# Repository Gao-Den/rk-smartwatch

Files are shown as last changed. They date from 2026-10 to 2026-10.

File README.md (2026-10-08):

<div align="center">

Repo Traffic

</div>

## RK Smartwatch

<div style="text-align: left;">
    <img src="rk-smartwatch-stm32f411/hardware/images/rk-smartwatch-overview.png" width=500"/>
</div>
<br>

RK Smartwatch is a smartwatch project developed with the purpose of being a showcase embedded product for applying the RK real-time operating system (Modern Preemptive RTOS) in embedded software development on microcontrollers

Key features:

- Display time, date, month, and year
- Gaming (with Flappy Bird built in)
- Weather forecast

### 1. Purpose
The product helps learners get hands-on with key concepts in embedded software development:

- Developing asynchronous applications on an Event-Driven architecture
- Building and organizing the user interface (UX/UI) with LVGL
- Firmware OTA: Over-the-air firmware updates for STM32 via nRF24L01
- Organizing data transmission and reception (Link) over physical media (Serial, RF, etc.)

### 2. Hardware
#### Components
<div style="text-align: left;">
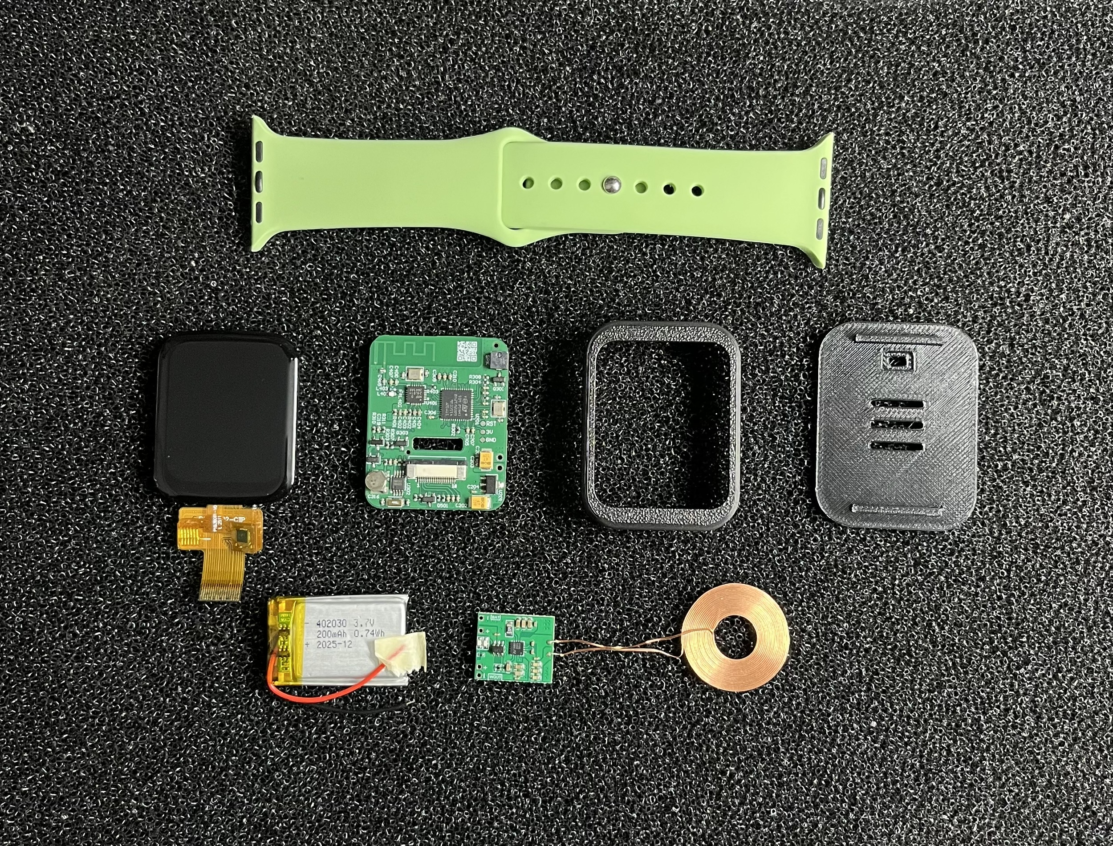
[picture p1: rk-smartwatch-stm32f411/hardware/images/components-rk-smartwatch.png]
    
</div>
<br>

The build consists of:
- Case (3D-printed)
- PCBA board
- Battery & Wireless charging
- Apple Watch strap

#### PCB Assembly
<div style="text-align: left;">
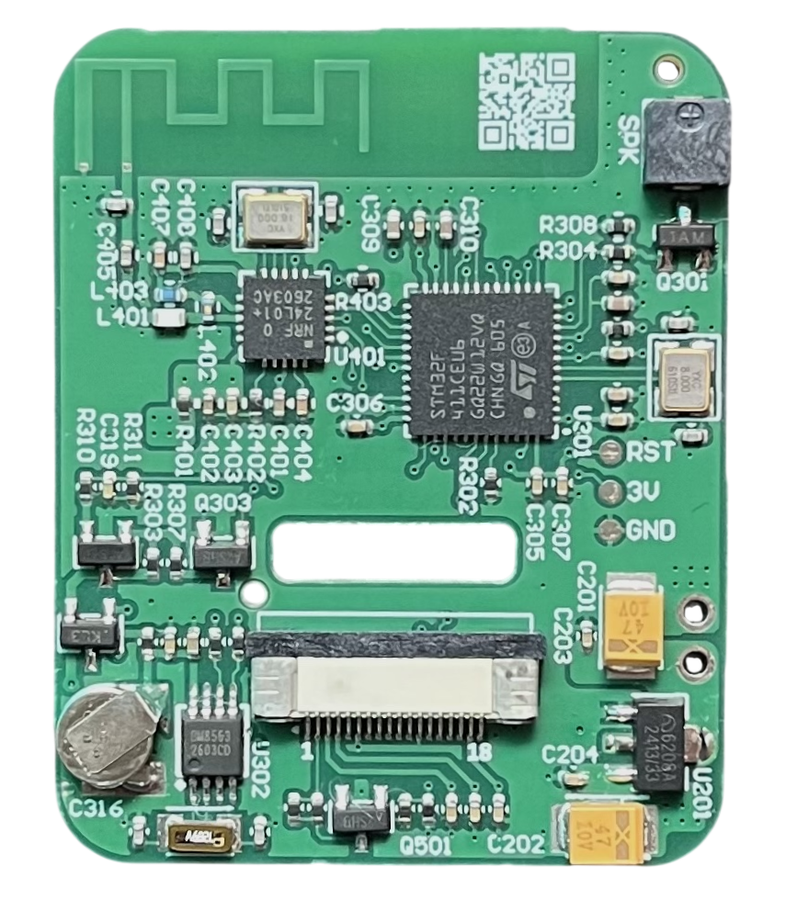
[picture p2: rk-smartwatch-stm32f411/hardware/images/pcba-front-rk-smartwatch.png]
    
</div>
<br>

The board is designed in accordance with DFM (Design for Manufacturing) standards.

Manufacturing resources: [Download](https://github.com/Gao-Den/rk-smartwatch/tree/main/rk-smartwatch-stm32f411/hardware/manufacturing)

#### Mechanical
<div style="text-align: left;">
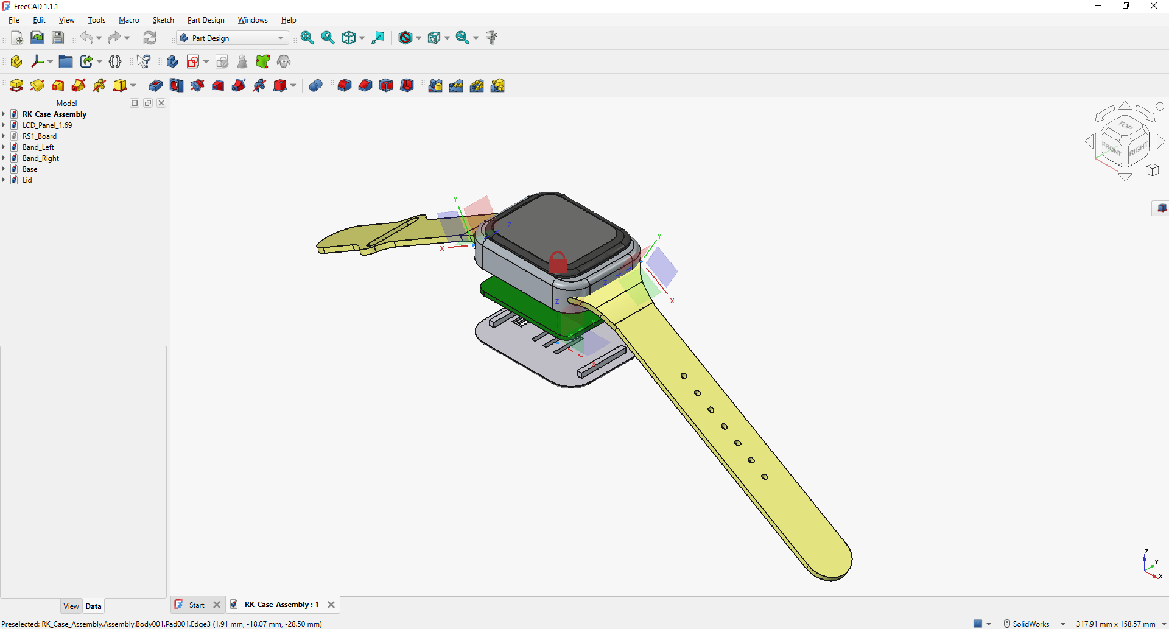
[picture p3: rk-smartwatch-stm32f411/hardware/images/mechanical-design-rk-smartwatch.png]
    
</div>
<br>

The project resources include the attached 3D-printable files.

3D Print: [Download](https://github.com/Gao-Den/rk-smartwatch/tree/main/rk-smartwatch-stm32f411/hardware/mechanical/3d-part)

#### UX/UI Design
<div style="text-align: left;">
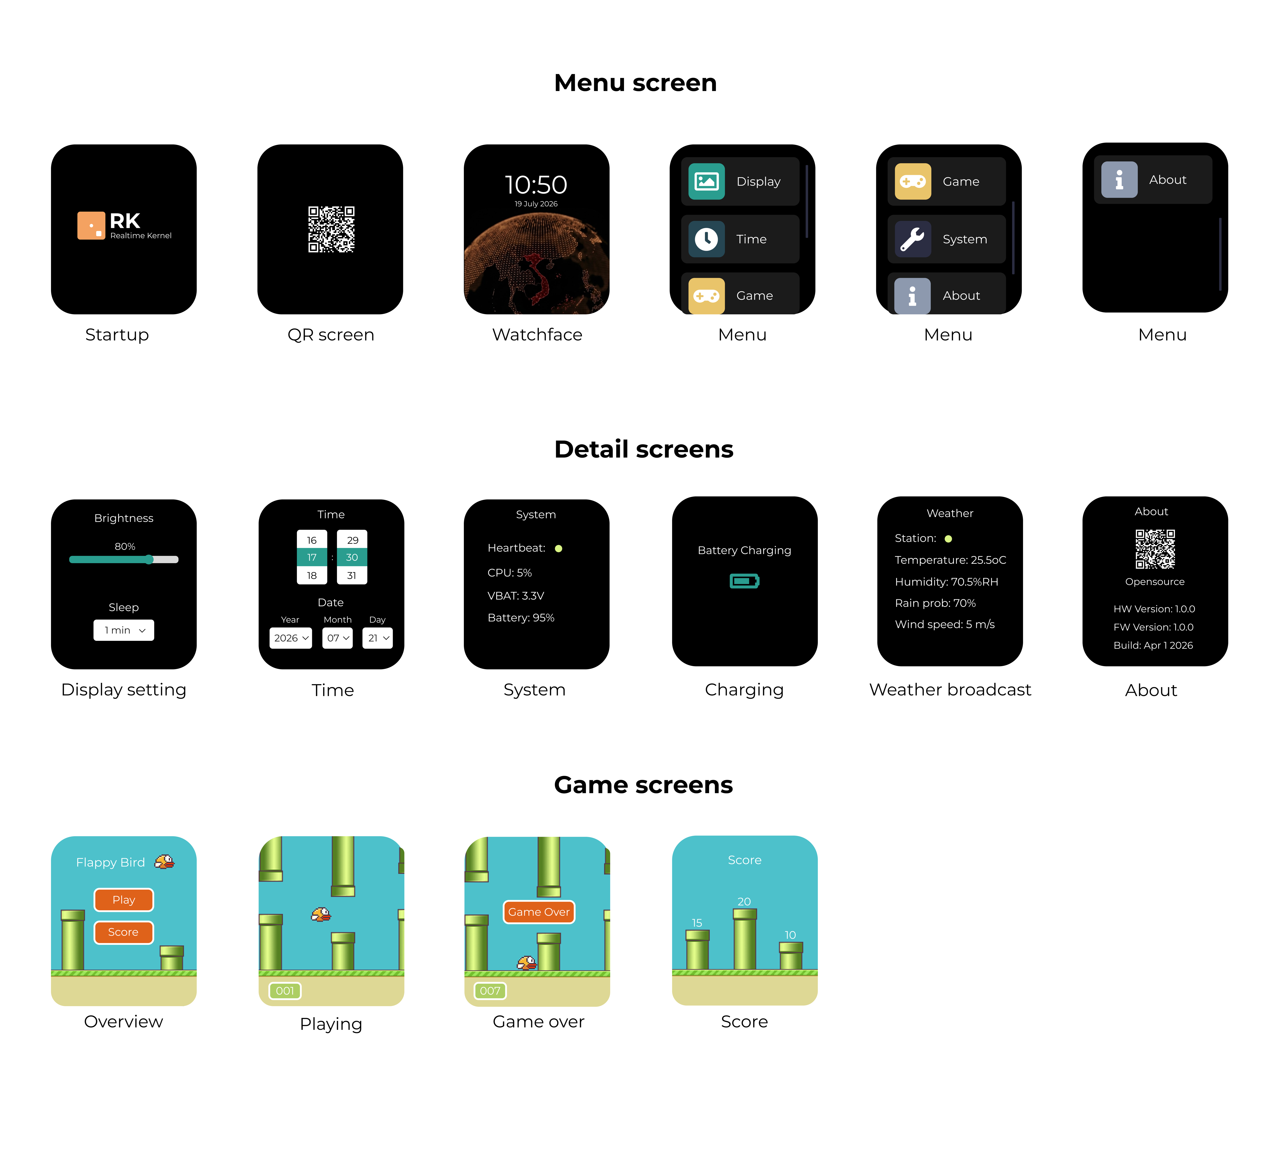
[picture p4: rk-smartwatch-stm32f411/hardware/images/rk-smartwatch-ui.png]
    
</div>
<br>

The interface and screen transitions are designed in Figma. Design reference: [Download](https://github.com/Gao-Den/rk-smartwatch/tree/main/rk-smartwatch-stm32f411/application/sources/app/screen/references)

### 3. Firmware:

| Resource | Description |
| --- | ---
| rk-smartwatch-stm32f411 | The RK Smartwatch |
| rk-flash | The firmware update application for the watch |
| rk-link | The programmer that takes data from the flashing application and packages it into packets for transmission over RF |
| esp32-s3-weather-station | The weather station that broadcasts weather packets to the watch over RF |

### 4. References:

| Topic | Link |
| --- | ---
| RKOS | https://github.com/Gao-Den/rkos |
| AK Embedded Base Kit | https://github.com/ak-embedded-software/ak-base-kit-stm32l151 |
| Active Object Model | https://www.state-machine.com/doc/AN_Active_Objects_for_Embedded.pdf |

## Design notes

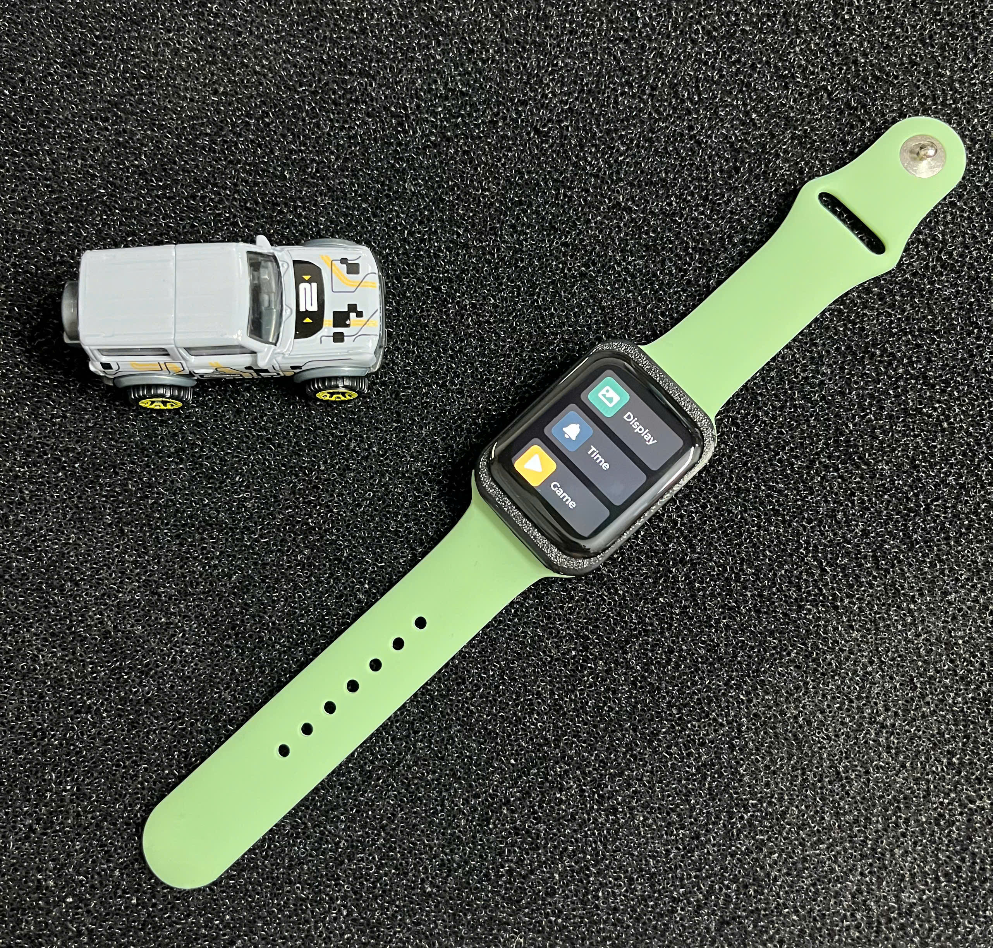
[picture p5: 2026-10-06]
rk-smartwatch-stm32f411/hardware/images/rk-smartwatch-overview.png

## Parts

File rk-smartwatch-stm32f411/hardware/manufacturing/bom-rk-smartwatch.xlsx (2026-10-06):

Smart Watch RS1.PrjPcb
# | Comment | Designator | Footprint | LCSC Part Number | Manufacturer Part Number | Manufacturer | Quantity | Description | Assembly Type | Link
1 | 47uF | C201, C202 | CASE-B_3528 | C136658 | CA45-B-10V-47uF-K | CEC(Shenzhen Zhenhua XinYun Elec) | 2 | 47uF 10V -55℃~+125℃ 2.4Ω@100kHz ±10% CASE-B-3528-19(mm) Tantalum Capacitors ROHS | SMT Assembly
2 | 0.1uF | C203, C204, C303, C304, C305, C306, C307, C308, C312, C313, C318, C501, C502, C503 | C_0402 | C1525 | CL05B104KO5NNNC | Samsung Electro-Mechanics | 14 | 100nF 0402 16V X7R ±10% Multilayer Ceramic Capacitors MLCC - SMD/SMT ROHS | SMT Assembly
3 | 22pF | C301, C302, C409, C410 | C_0402 | C1555 | 0402CG220J500NT | FH (Guangdong Fenghua Advanced Tech) | 4 | 22pF 0402 50V C0G ±5% Multilayer Ceramic Capacitors MLCC - SMD/SMT ROHS | SMT Assembly
4 | 4.7uF | C309, C310, C311 | C_0402 | C23733 | CL05A475MP5NRNC | Samsung Electro-Mechanics | 3 | 4.7uF 0402 10V X5R ±20% Multilayer Ceramic Capacitors MLCC - SMD/SMT ROHS | SMT Assembly
5 | 12pF | C314, C315 | C_0402 | C1547 | 0402CG120J500NT | FH (Guangdong Fenghua Advanced Tech) | 2 | 12pF 0402 50V C0G ±5% Multilayer Ceramic Capacitors MLCC - SMD/SMT ROHS | SMT Assembly
6 | 1uF | C317, C401 | C_0402 | C52923, C157353 | CL05A105KA5NQNC, 0402X105K100NT | Samsung Electro-Mechanics, FH (Guangdong Fenghua Advanced Tech) | 2 | 1uF 0402 16V X7R ±10% Multilayer Ceramic Capacitors MLCC - SMD/SMT ROHS, 1uF 0402 10V X5R ±10% Multilayer Ceramic Capacitors MLCC - SMD/SMT ROHS | SMT Assembly
7 | 10nF | C319, C403 | C_0402 | C15195, C1524 | CL05B103KB5NNNC, 0402B103K500NT | Samsung Electro-Mechanics, FH (Guangdong Fenghua Advanced Tech) | 2 | 10nF 0402 50V X7R ±10% Multilayer Ceramic Capacitors MLCC - SMD/SMT ROHS | SMT Assembly
8 | 1nF | C402 | C_0402 | C1523 | 0402B102K500NT | FH (Guangdong Fenghua Advanced Tech) | 1 | 1nF 0402 50V X7R ±10% Multilayer Ceramic Capacitors MLCC - SMD/SMT ROHS | SMT Assembly
9 | 33nF | C404 | C_0402 | C60425 | 0402B333K160NT | FH (Guangdong Fenghua Advanced Tech) | 1 | 33nF 0402 16V X7R ±10% 0402 Multilayer Ceramic Capacitors MLCC - SMD/SMT ROHS | SMT Assembly
10 | 1.5pF | C405 | C_0402 | C1552 | 0402CG1R5C500NT | FH (Guangdong Fenghua Advanced Tech) | 1 | 1.5pF 0402 50V C0G Multilayer Ceramic Capacitors MLCC - SMD/SMT ROHS | SMT Assembly
11 | 1pF | C406 | C_0402 | C1550 | 0402CG1R0C500NT | FH (Guangdong Fenghua Advanced Tech) | 1 | 1pF 0402 50V C0G Multilayer Ceramic Capacitors MLCC - SMD/SMT ROHS | SMT Assembly
12 | 2.2nF | C407 | C_0402 | C1531 | 0402B222K500NT | FH (Guangdong Fenghua Advanced Tech) | 1 | 2.2nF 0402 50V X7R ±10% Multilayer Ceramic Capacitors MLCC - SMD/SMT ROHS | SMT Assembly
13 | 4.7pF | C408 | C_0402 | C1569 | 0402CG4R7C500NT | FH (Guangdong Fenghua Advanced Tech) | 1 | 4.7pF 0402 50V C0G Multilayer Ceramic Capacitors MLCC - SMD/SMT ROHS | SMT Assembly
14 | BAT54C | D301 | SOT-23-3_L2.9-W1.6-P1.90-LS2.8-BR | C14308 | BAT54CLT1G | ON Semicon | 1 | SCHOTTKY BARRIER DIODES (SBD) SOT-23(SOT-23-3) ROHS | SMT Assembly
15 | FPC-05F-18PH20 | J501 | FPC-SMD_18P-P0.50_FPC-05F-18PH20 | C2856802 | FPC-05F-18PH20 | XUNPU | 1 | -25℃~+85℃ 0.3mm 0.5mm 18P 2mm 500mA 50V Bottom Contact Hinged Lid Phosphor bronze Surface Mount, Right Angle Tin SMD,P=0.5mm,Surface Mount，Right Angle FFC, FPC (Flat Flexible) Connector Assemblies ROHS | SMT Assembly
16 | 3.9nH | L401 | L_0402 | C317939 | FHW0402UC3N9JST | FH (Guangdong Fenghua Advanced Tech) | 1 | 3.9nH 840mA ±5% 66mΩ 0402 Inductors (SMD) ROHS | SMT Assembly
17 | 8.2nH | L402 | L_0402 | C317946 | FHW0402UC8N2JST | FH (Guangdong Fenghua Advanced Tech) | 1 | 8.2nH 680mA ±5% 100mΩ 0402 Inductors (SMD) ROHS | SMT Assembly
18 | 2.7nH | L403 | L_0402 | C317935 | FHW0402UC2N7KST | FH (Guangdong Fenghua Advanced Tech) | 1 | 2.7nH 640mA ±10% 120mΩ 0402 Inductors (SMD) ROHS | SMT Assembly
19 | FUET-4020C | LS301 | Buzzer SMD | C41410568 | FUET-4020C | FUET | 1 | -30℃~+70℃ 100mA 2V~4V 2mm 3V 4kHz 4mm 4mm SMD SMD,4x4mm Buzzers ROHS | SMT Assembly
20 | MMBT3904 | Q301 | SOT-23-3 | C20526 | MMBT3904 | Changjiang Electronics Tech (CJ) | 1 | MMBT3904 TRANSISTORS (NPN/PNP) NPN 200MA 40V SOT-23(SOT-23-3) ROHS | SMT Assembly
21 | SI2301 | Q302 | SOT-23-3_L2.9-W1.3-P1.90-LS2.4-BR | C10487 | SI2301CDS-T1-GE3 | Vishay Intertech | 1 | 1 P-Channel 1.6W -55℃~+150℃ 10nC@4.5V 142mΩ@2.5V 1V 20V 3.1A 405pF 55pF 75pF P-Channel SOT-23 MOSFETs ROHS | SMT Assembly
22 | SI2302CDS | Q303, Q501 | SOT-23-3_L2.9-W1.3-P1.90-LS2.4-BR | C10488 | Si2302CDS-T1-GE3 | Vishay Intertech | 2 | 1 N-channel 2.9A 20V 3.5nC@10V,4.5V 550mW 75mΩ@2.5V 850mV N-Channel SOT-23 MOSFETs ROHS | SMT Assembly
23 | 10k | R301, R302, R308, R311, R504 | R_0402 | C25744 | 0402WGF1002TCE | UNI-ROYAL(Uniroyal Elec) | 5 | 10kΩ 0402 50V 62.5mW Thick Film Resistors ±1% Chip Resistor - Surface Mount ROHS | SMT Assembly
24 | 100k | R303 | R_0402 | C25741 | 0402WGF1003TCE | UNI-ROYAL(Uniroyal Elec) | 1 | 100kΩ 0402 50V -55℃~+155℃ 62.5mW Thick Film Resistor ±1% ±100ppm/℃ Chip Resistor - Surface Mount ROHS | SMT Assembly
25 | 1k | R304, R503 | R_0402 | C11702 | 0402WGF1001TCE | UNI-ROYAL(Uniroyal Elec) | 2 | 1kΩ 0402 50V 62.5mW Thick Film Resistors ±1% Chip Resistor - Surface Mount ROHS | SMT Assembly
26 | 4.7k | R305, R306 | R_0402 | C25900 | 0402WGF4701TCE | UNI-ROYAL(Uniroyal Elec) | 2 | 4.7kΩ 0402 50V -55℃~+155℃ 62.5mW Thick Film Resistor ±1% ±100ppm/℃ Chip Resistor - Surface Mount ROHS | SMT Assembly
27 | 0R | R307, R401 | R_0402 | C17168 | 0402WGF0000TCE | UNI-ROYAL(Uniroyal Elec), Uniroyal Elec | 2 | 0Ω 0402 50V -55℃~+155℃ 62.5mW Thick Film Resistor ±1% ±800ppm/℃ Chip Resistor - Surface Mount ROHS, 0Ω 0402 62.5mW Thick Film Resistors 50V ±800ppm/℃ ±1%Chip Resistor - Surface Mount ROHS | SMT Assembly
28 | 120R | R309 | R_0402 | C25079 | 0402WGF1200TCE | UNI-ROYAL(Uniroyal Elec) | 1 | 120Ω 0402 50V -55℃~+155℃ 62.5mW Thick Film Resistor ±1% ±100ppm/℃ Chip Resistor - Surface Mount ROHS | SMT Assembly
29 | 20k | R310 | R_0402 | C25765 | 0402WGF2002TCE | UNI-ROYAL(Uniroyal Elec) | 1 | 20kΩ 0402 50V 62.5mW Thick Film Resistors ±1% Chip Resistor - Surface Mount ROHS | SMT Assembly
30 | 22k | R402 | R_0402 | C25768 | 0402WGF2202TCE | Uniroyal Elec | 1 | 22kΩ 0402 62.5mW Thick Film Resistors 50V ±100ppm/℃ ±1% Chip Resistor - Surface Mount ROHS | SMT Assembly
31 | 22R | R403 | R_0402 | C25092 | 0402WGF220JTCE | Uniroyal Elec | 1 | 22Ω 0402 62.5mW Thick Film Resistors 50V ±1% ±100ppm/℃ Chip Resistor - Surface Mount ROHS | SMT Assembly
32 | 220R | R501, R502 | R_0402 | C25091 | 0402WGF2200TCE | UNI-ROYAL(Uniroyal Elec) | 2 | 220Ω 0402 50V -55℃~+155℃ 62.5mW Thick Film Resistor ±1% ±100ppm/℃ Chip Resistor - Surface Mount ROHS | SMT Assembly
33 | ME6208A30PG | U201 | SOT_89 | C80196 | ME6208A30PG | MICRONE(Nanjing Micro One Elec) | 1 | -45℃~+150℃ 1 150mA 18V 3V 3uA Fixed Positive SOT-89 Voltage Regulators - Linear, Low Drop Out (LDO) Regulators ROHS | SMT Assembly
34 | STM32F411CEU6 | U301 | UFQFPN-48_L7.0-W7.0-P0.50-BL-EP | C60420 | STM32F411CEU6 | STMicroelectronics | 1 | -40℃~+85℃ 1.7V~3.6V 100MHz 128KB 12bit 32 Bit 36 512KB ARM Cortex-M4 Built-in FLASH UFQFPN-48(7x7) Microcontrollers (MCU/MPU/SOC) ROHS | SMT Assembly
35 | BM8563EMA | U302 | MSOP-8_L3.0-W3.0-P0.65-LS5.0-BL | C269878 | BM8563EMA | GATEMODE(捷茂微) | 1 | MSOP-8 Real-time Clocks (RTC) ROHS | SMT Assembly
36 | NRF24L01P-R | U401 | QFN-20_L4.0-W4.0-P0.50-BL-EP | C8791 | NRF24L01P-R | NORDIC | 1 | NRF24L01P-R SPI QFN-20_4x4x05P RF Transceiver ICs ROHS | SMT Assembly
37 | 8MHz | X301 | CRYSTAL_SMD3225_4P | C2682774 | X32258MSB4SI | YXC Crystal Oscillators | 1 | 8MHz 20pF 120Ω -40℃~+85℃ Crystal Oscillator ±10ppm ±20ppm SMD3225-4P Crystals ROHS | SMT Assembly
38 | 32.768kHz | X302 | CRYSTAL-SMD_L3.2-W1.5 | C841881 | Q13FC13500005 | Seiko Epson | 1 | 32.768kHz 12.5pF ±10ppm SMD3215-2P Crystals ROHS | SMT Assembly
39 | 16Mhz | X401 | SMD-3225_4P | C13738 | X322516MLB4SI | Yangxing Tech | 1 | 16MHz SMD Crystal Resonator 9pF ±10ppm ±30ppm -40℃~+85℃ SMD3225-4P Crystals ROHS | SMT Assembly

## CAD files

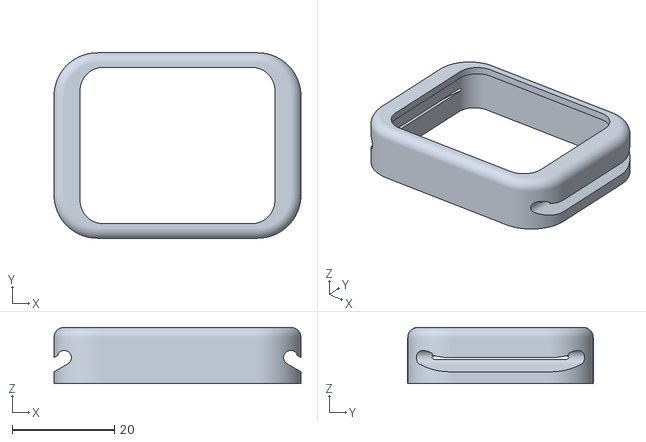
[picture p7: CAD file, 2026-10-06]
rk-smartwatch-stm32f411/hardware/mechanical/3d-part/base-cover-rk-smartwatch.stl
48.2 x 36.2 x 11.0

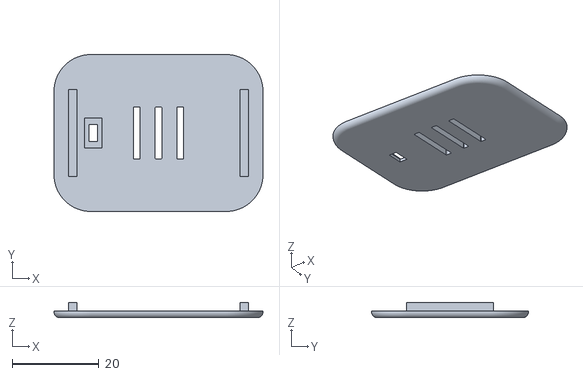
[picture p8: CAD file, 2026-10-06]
rk-smartwatch-stm32f411/hardware/mechanical/3d-part/lid-rk-smartwatch.stl
48.1 x 36.1 x 3.50

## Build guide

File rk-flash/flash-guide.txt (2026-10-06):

.\rk-flash.exe COM20 D:\GaoDen\dev\rk-smartwatch-stm32f411\application\build\rk-smartwatch-stm32f411-v1.0.0.bin 0

.\rk-flash.exe COM20 D:\GaoDen\dev\rk-smartwatch-stm32f411\boot\build\rk-smartwatch-stm32f411-boot-v1.0.0.bin 1

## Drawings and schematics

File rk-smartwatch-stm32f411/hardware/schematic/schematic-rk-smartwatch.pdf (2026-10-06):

# Power.SchD

o

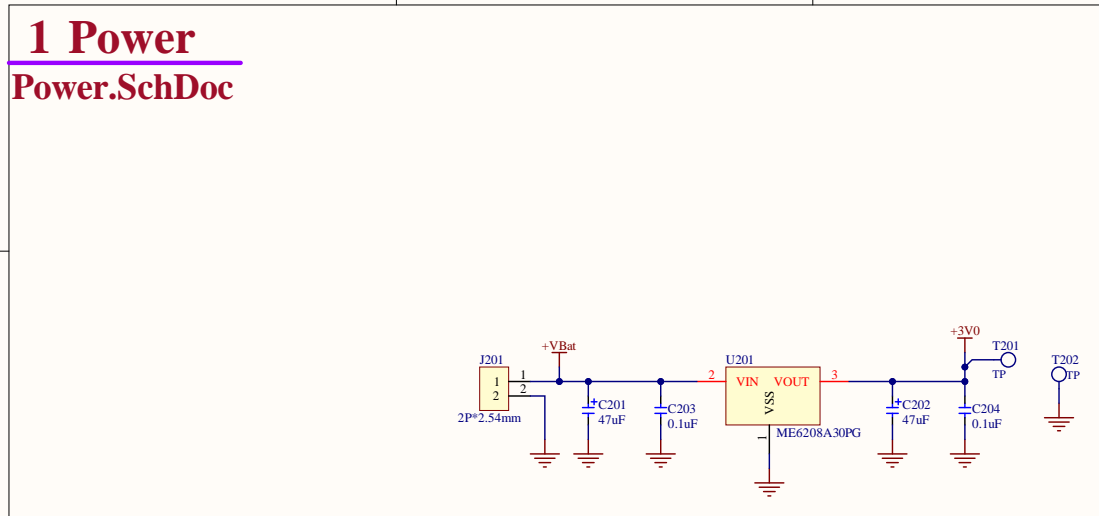
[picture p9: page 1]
DWG; wer.Sch; Smart; Watch RS1.PrjPcb; SmartWatch; 1 Powe r; VSS 1; +VBat

# MCU.SchDoc

# 2 MCU

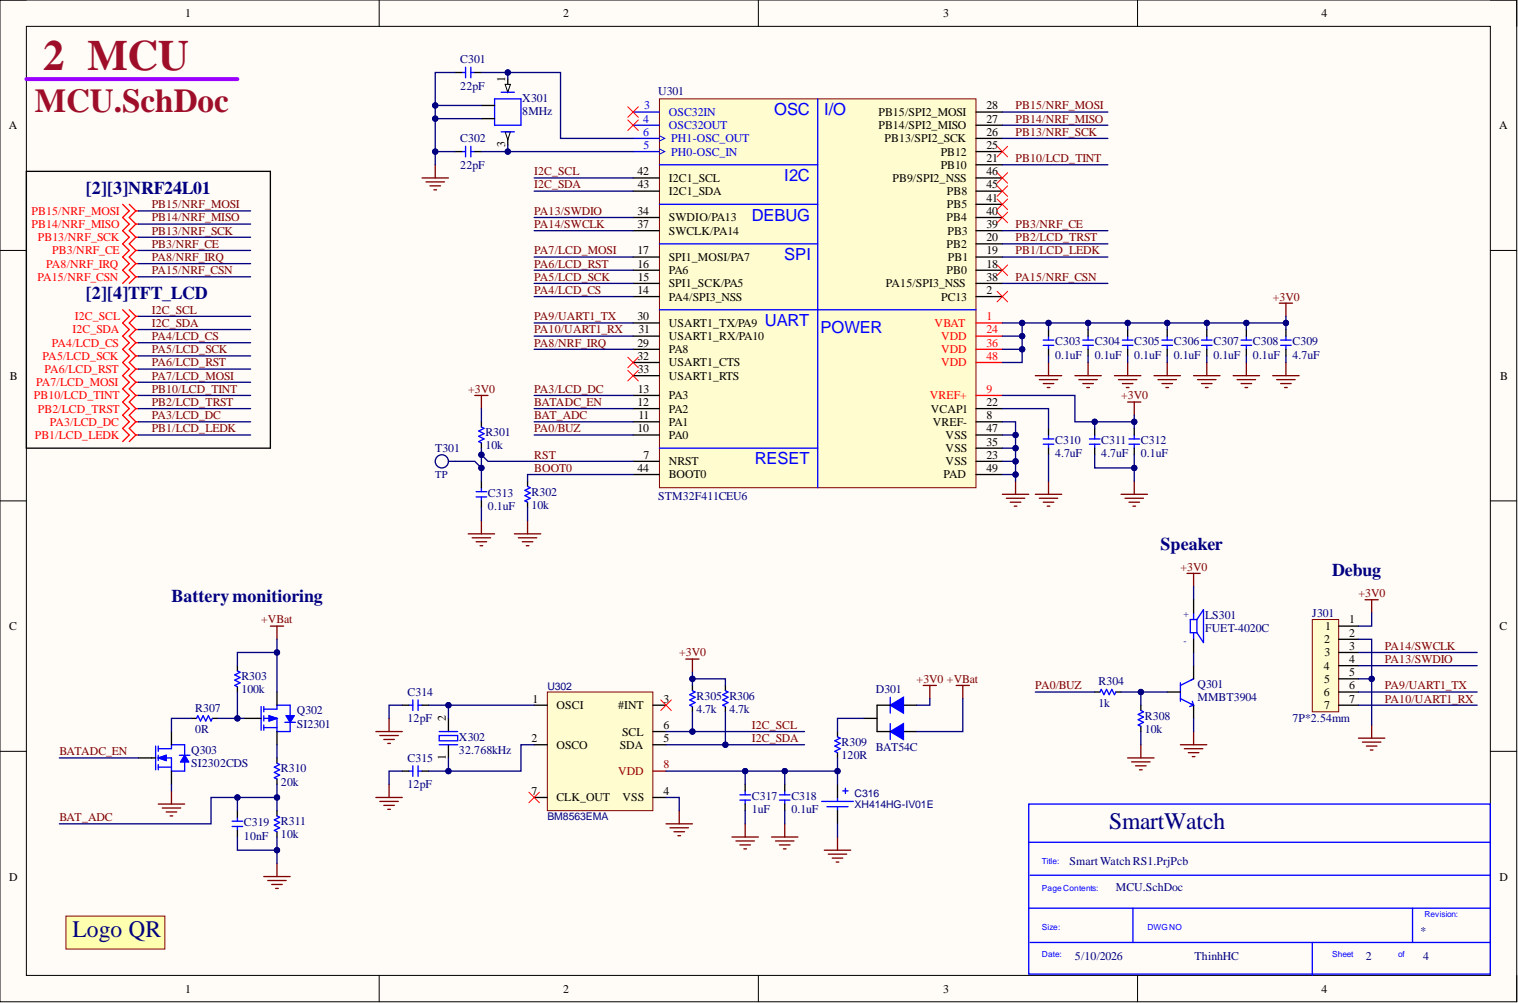
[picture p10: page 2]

# NRF24L01-M.SchDoc

# 3NRF24L01-M

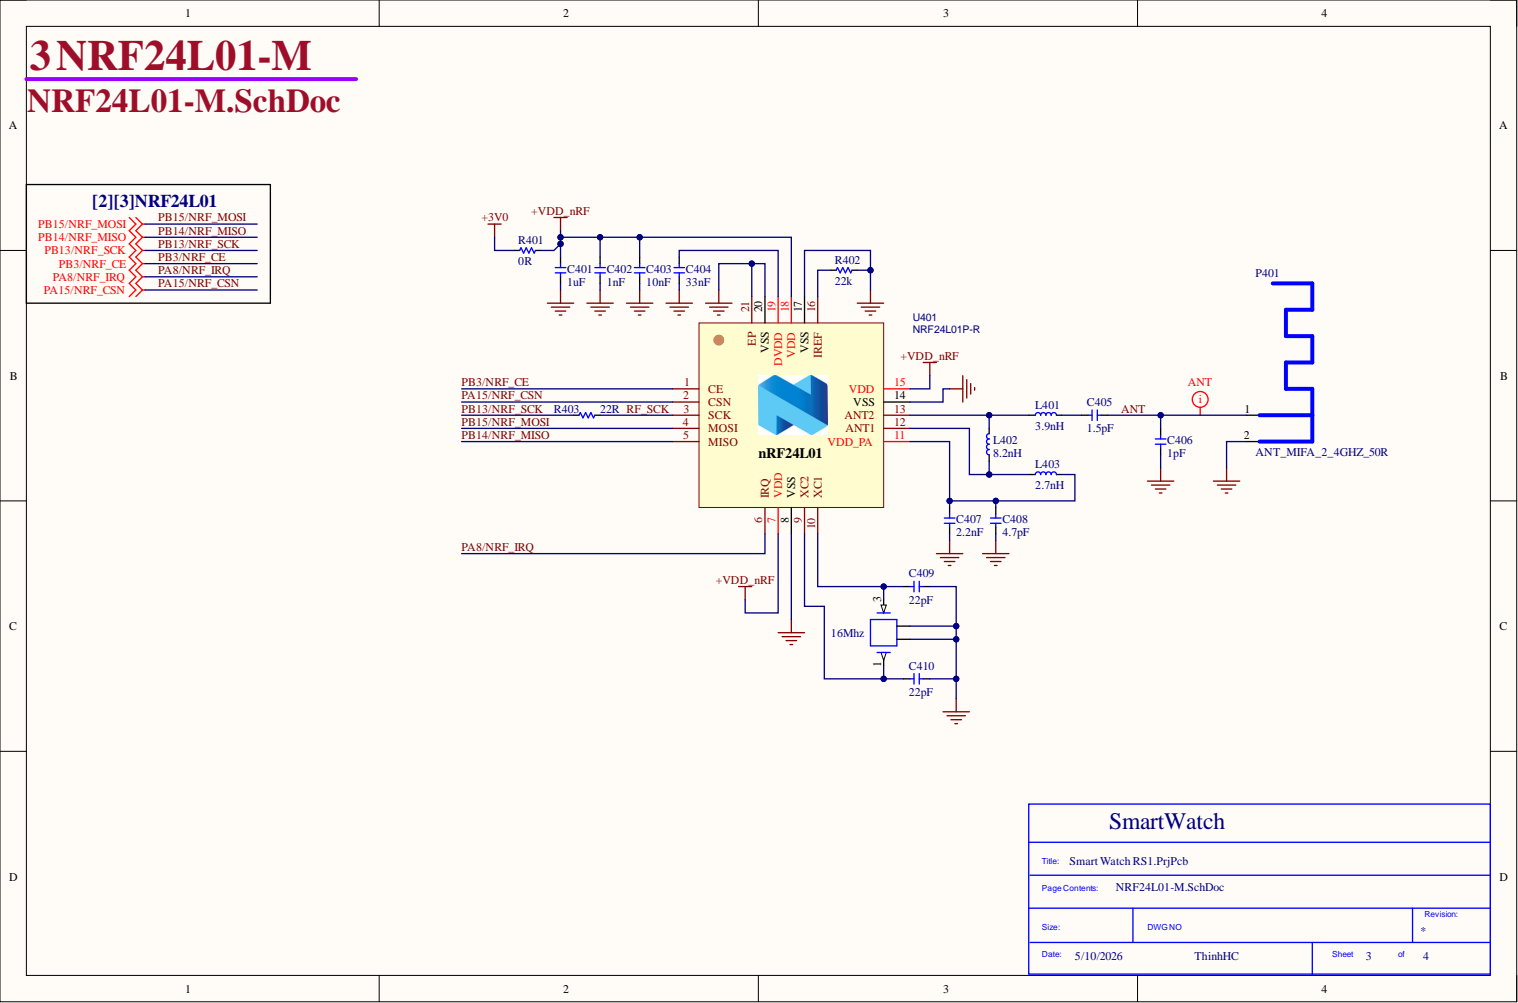
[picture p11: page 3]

IREF 16 VSS 17 VDD 18 DVDD 19 VSS 20 EP 21 nRF24L01

# TFT_LCD.Sch

D

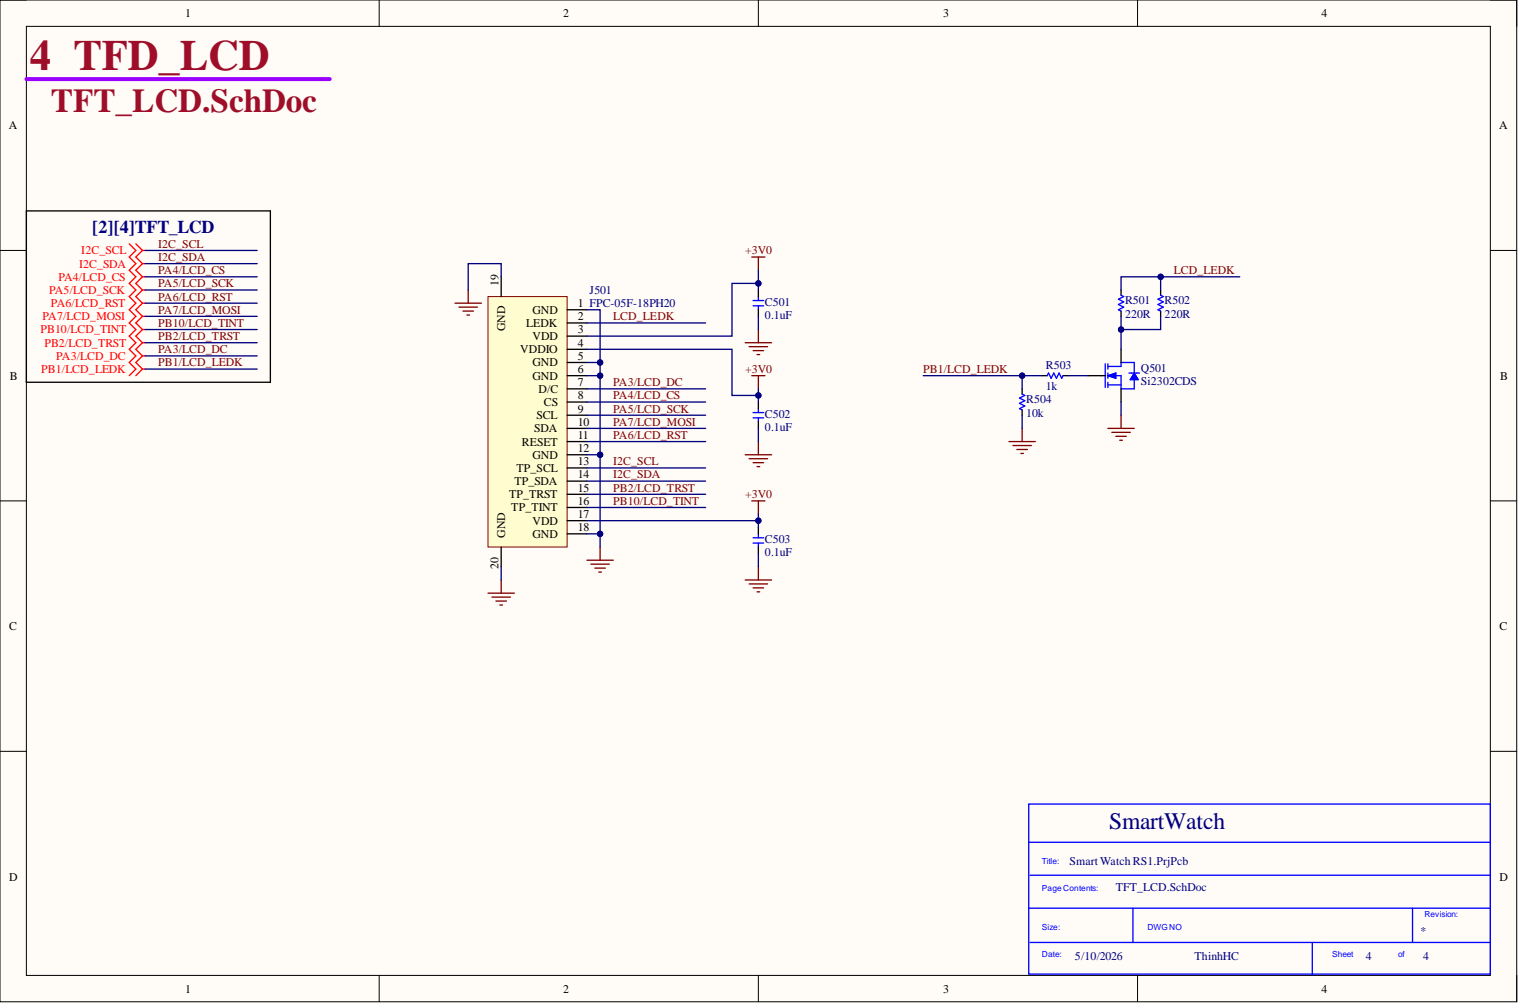
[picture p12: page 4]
I2C_SCL I2C_; A I2C_SCL I2C_; LCD; T PB10/LCD_TINT; DWG; TFT; LCD.Sch; Smart; Watch RS1.PrjPcb; SmartWatch; 4 TFD_LCD; SCL; RESE; TP_SCL; GND 19 GND 20; 1 FPC-0

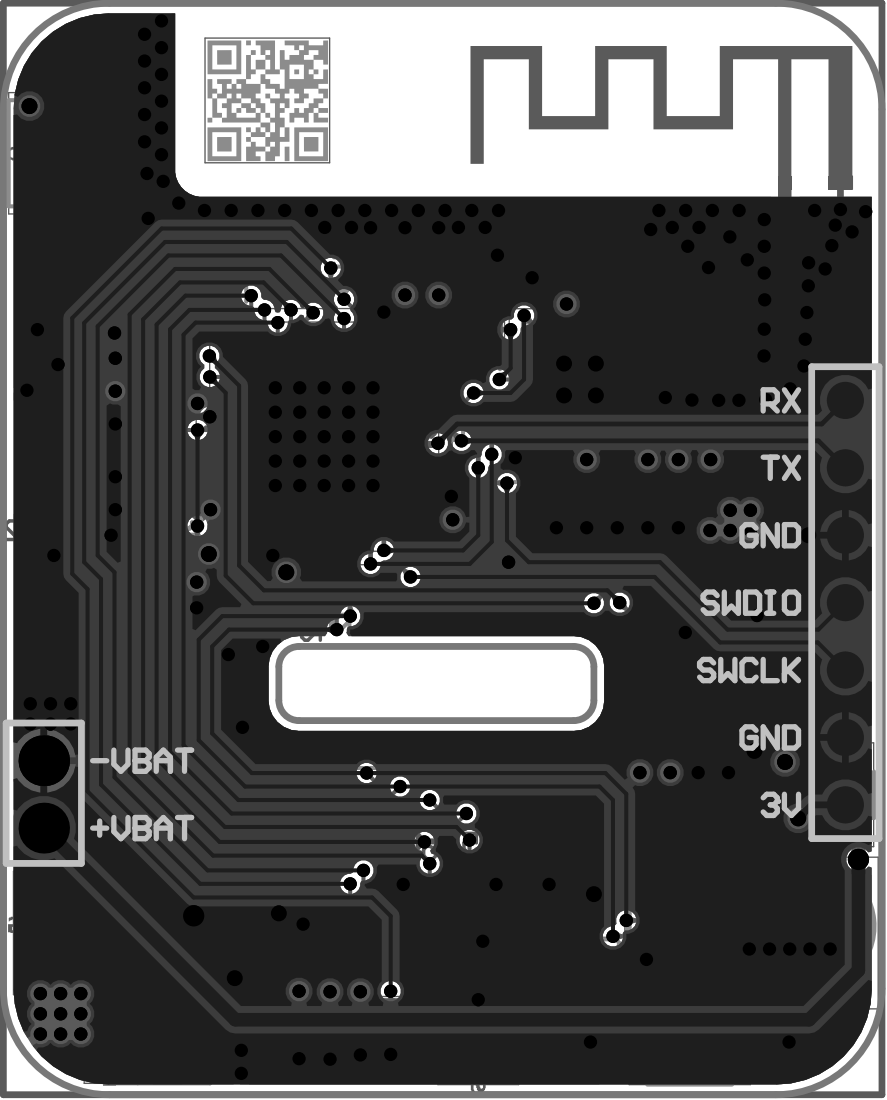
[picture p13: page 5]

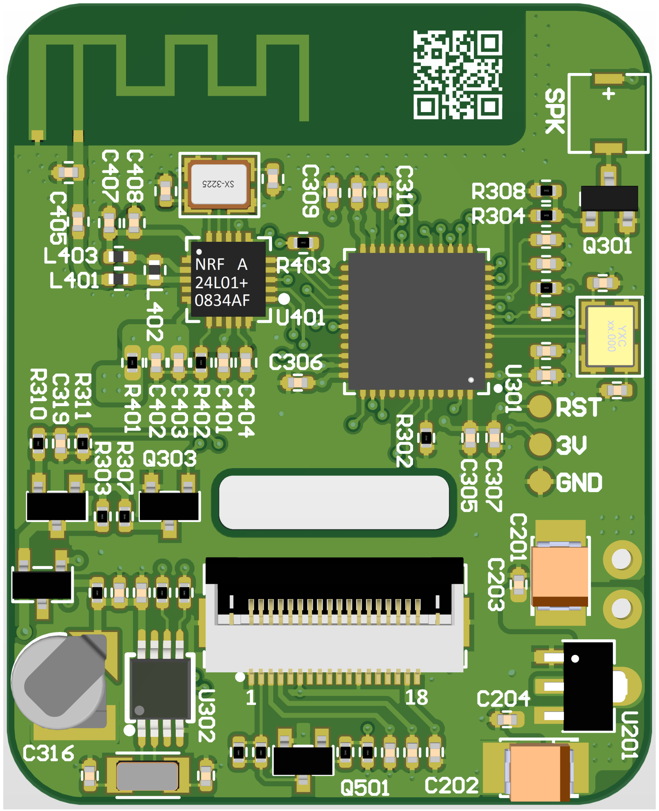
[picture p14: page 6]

# | Comment Designato | | Footprint LCSC Part NumbMeanufacturer Part Number | | | Manufacturer | Quantity | Description | Assembly Type | Link

1 | 47uF | C201, CCASE-B_3528 | | C136658 | CA45-B-10V-47uF-K | CEC(Shenzhen Zhenhua XinYu | 2 | 47uF 10V -55℃~+125℃SMTAssembly
2 | 0.1uF | C203, CC_0402 | | C1 525 | L5B104KO 5NNN | Sam sungEl ectro -Mechanics | 14 | 100nF 0402 16V X7R ±1SMTAssemb ly
3 | 22pF | C301, CC_0402 | | C1555 | 0402CG220J500NT | FH (Guangdong Fenghua Adva | 4 | 22pF 0402 50V C0G ±5%SMTAssem bly
4 | 4.7uF | C309, CC_0402 | | C23733 | CL05A475MP5NRNC | Samsung Electro-Mechanics | 3 | 4.7uF 0402 10V X5R ±2SMTAssem bly
5 | 12pF | C314, CC_0402 | | C1547 | 0402CG120J500NT | FH (Guangdong Fenghua Adva | 2 | 12pF 0402 50V C0G ±5%SMTAssem bly
6 | 1uF | C317, CC_0402 | | C52923, C15735CL05A105KA5NQNC, 0402XSamsungElectro-Mechanics, F | | | 2 | 1uF040216VX7R±10%SM TAsse mbly
7 | 10nF | C319, CC_0402 | | C15195, C1524 | CL05B103KB5NNNC, 0402B1SamsungElectro-Mechanics, F | | 2 | 10nF040250VX7R±10SM TAssem bly
8 | 1nF | C402 | C_0402 | C1523 | 0402B102K500NT | FH (Guangdong Fenghua Adva | 1 | 1nF 0402 50V X7R ±10%SMTAsse mbly
9 | 33nF | C404 | C_0402 | C60425 | 0402B333K160NT | FH (Guangdong Fenghua Adva | 1 | 33nF 0402 16V X7R ±10SM TAssembly
10 | 1.5pF | C405 | C_0402 | C1552 | 0402CG1R5C500NT | FH (Guangdong Fenghua Adva | 1 | 1.5pF 0402 50V C0G MSMTA ssembly
11 | 1pF | C406 | C_0402 | C1550 | 0402CG1R0C500NT | FH (Guangdong Fenghua Adva | 1 | 1pF 0402 50V C0G MultSMT Assembly
12 | 2.2nF | C407 | C_0402 | C1531 | 0402B222K500NT | FH (Guangdong Fenghua Adva | 1 | 2.2nF 0402 50V X7R ±1SMTAssem bly
13 | 4.7pF | C408 | C_0402 | C1569 | 0402CG4R7C500NT | FH (Guangdong Fenghua Adva | 1 | 4.7pF 0402 50V C0G MuSMTA ssmbly
14 | BAT54C | D301 | SOT-23-3_L2.9-W1.6C14308 | | BAT54CLT1G | ON Semicon | 1 | SCHOTTKY BARRIER DSMT Ass embly
15 | FPC-05F-18PH20 | J501 | FPC-SMD_18P-P0.5C2856802 | | FPC -05F-18PH20 | XUNPU | 1 | -25℃~+85℃ 0.3mm 0.5SMTAs sembly
16 | 3.9nH | L401 | L_0402 | C317939 | FHW0402UC3N9JST | FH (Guangdong Fenghua Adva | 1 | 3.9nH 840mA ±5% 66mSMTAssembly
17 | 8.2nH | L402 | L_0402 | C317946 | FHW0402UC8N2JST | FH (Guangdong Fenghua Adva | 1 | 8.2nH 680mA ±5% 100mSM TAssembly
18 | 2.7nH | L403 | L_0402 | C317935 | FHW0402UC2N7KST | FH (Guangdong Fenghua Adva | 1 | 2.7nH 640mA ±10% 120SMTAssembly
19 | FUET-4020C | LS301 | Buzzer SMD | C41410568 | FUET-4020C | FUET | 1 | -30℃~+70℃ 100mA 2VSMTAssembly
20 | MMBT3904 | Q301 | SOT-23-3 | C20526 | MMBT3904 | Changjiang Electronics Tech (C | 1 | MMBT3904 TRANSISTOSM TAssemb ly
21 | SI2301 | Q302 | SOT-23-3_L2.9-W1.3C10487 | | SI2301CDS-T1-GE3 | Vishay Intertech | 1 | 1 P-Channel 1.6W -55℃SMTAssembly
22 | SI2302CDS | Q303, QSOT-23-3_L2.9-W1.3C10488 | | | Si2302CDS-T1-GE3 | Vishay Intertech | 2 | 1 N-channel 2.9A 20V 3.SMTAssembly
23 | 10k | R301, RR_0402 | | C25744 | 0402WGF1002TCE | UNI-ROYAL(Uniroyal Elec) | 5 | 10kΩ 0402 50V 62.5mWSMTAssembly
24 | 100k | R303 | R_0402 | C25741 | 0402WGF1003TCE | UNI-ROYAL(Uniroyal Elec) | 1 | 100kΩ 0402 50V -55℃~SMTAssembly
25 | 1k | R304, RR_0402 | | C11702 | 0402WGF1001TCE | UNI-ROYAL(Uniroyal Elec) | 2 | 1kΩ 0402 50V 62.5mW | SMTAssembly
26 | 4.7k | R305, RR_0402 | | C25900 | 0402WGF4701TCE | UNI-ROYAL(Uniroyal Elec) | 2 | 4.7kΩ 0402 50V -55℃~+SMTAssembly
27 | 0R | R307, RR_0402 | | C17168 | 0402WGF0000TCE | UNI-ROYAL(Uniroyal Elec), Uni | 2 | 0Ω 0402 50V -55℃~+15SMTAssembly
28 | 120R | R309 | R_0402 | C25079 | 0402WGF1200TCE | UNI-ROYAL(Uniroyal Elec) | 1 | 120Ω 0402 50V -55℃~+SMTAssembly
29 | 20k | R310 | R_0402 | C25765 | 0402WGF2002TCE | UNI-ROYAL(Uniroyal Elec) | 1 | 20kΩ 0402 50V 62.5mWSMTAssembly
30 | 22k | R402 | R_0402 | C25768 | 0402WGF2202TCE | Uniroyal Elec | 1 | 22kΩ 0402 62.5mW ThiSM TAssembly
31 | 22R | R403 | R_0402 | C25092 | 0402WGF220JTCE | Uniroyal Elec | 1 | 22Ω 0402 62.5mW ThicSMTAssembly
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

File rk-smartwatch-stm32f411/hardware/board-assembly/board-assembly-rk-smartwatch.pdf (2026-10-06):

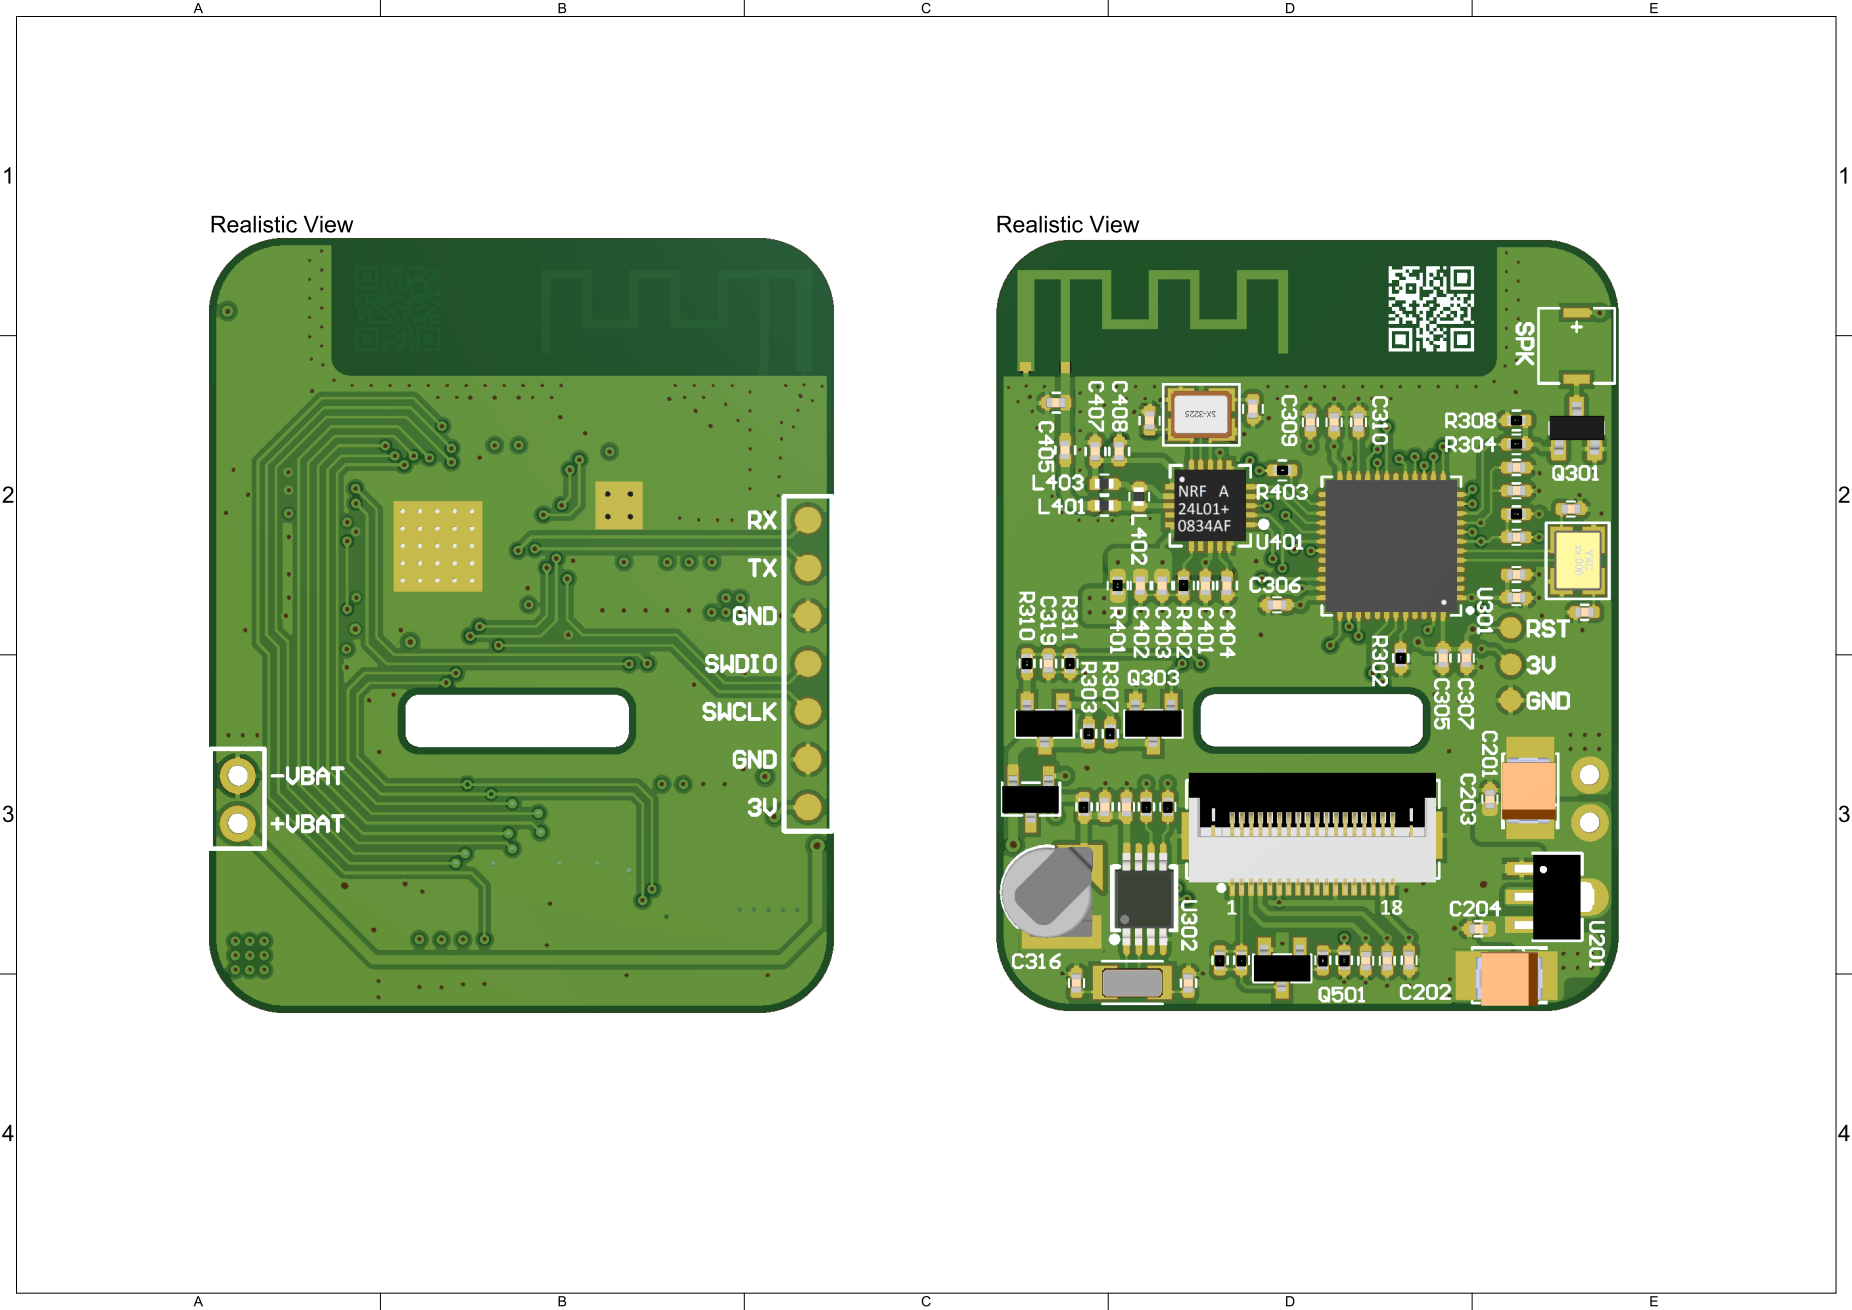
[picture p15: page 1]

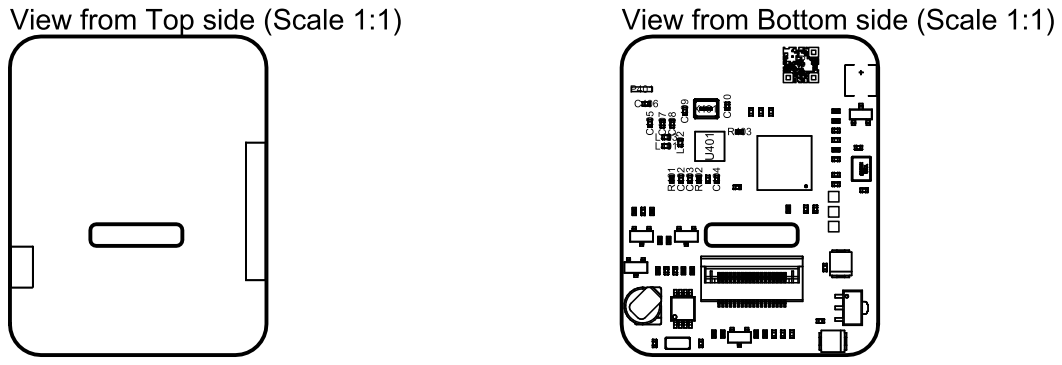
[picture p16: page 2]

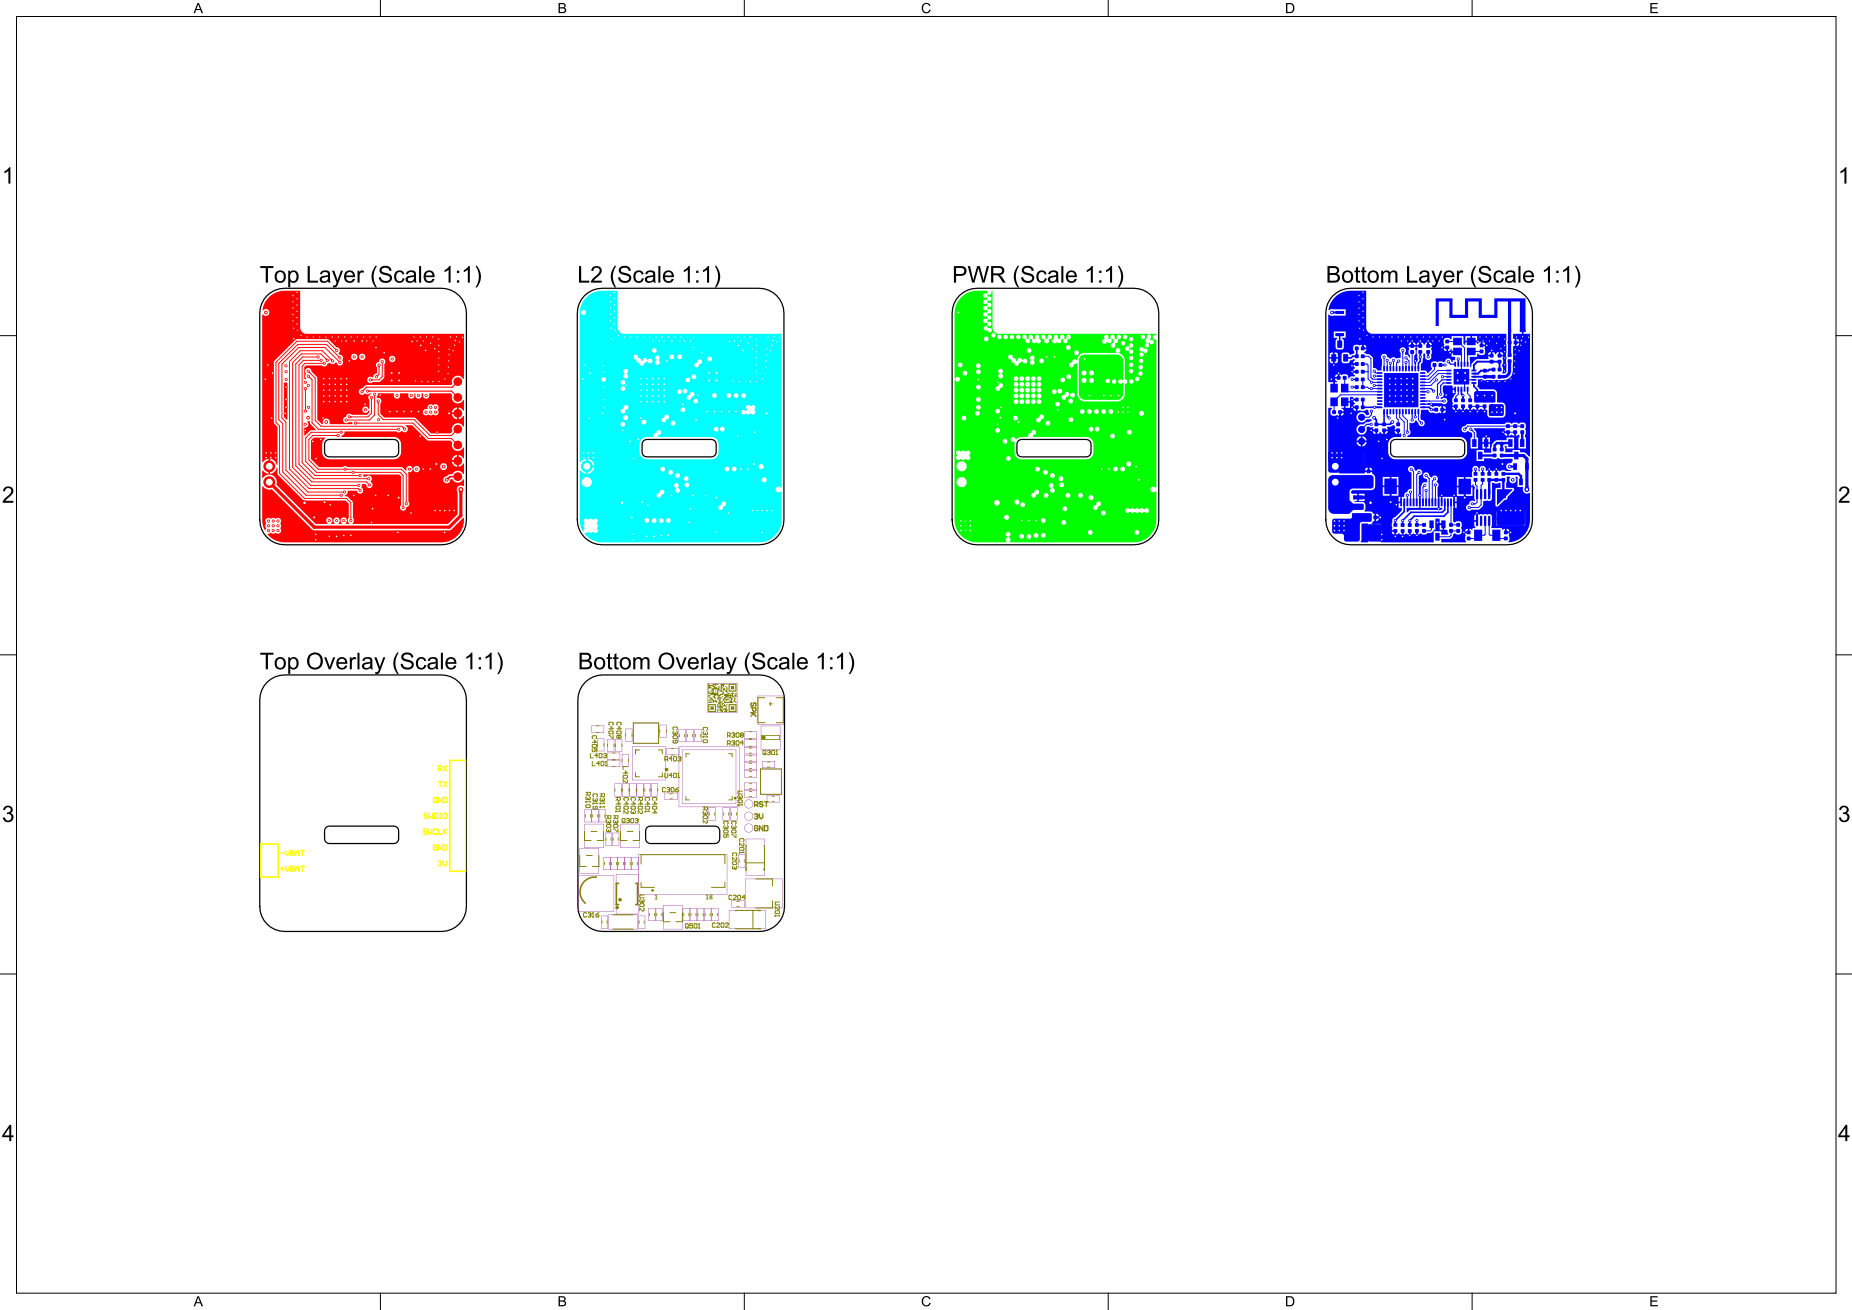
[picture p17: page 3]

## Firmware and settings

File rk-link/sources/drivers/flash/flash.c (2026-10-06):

/**
 ******************************************************************************
 * @file: flash.c
 * @brief: external flash function for W25Q256JVEIQTR NOR Flash
 * @date: 27/08/2024
 * @author: GaoKong
 ******************************************************************************
**/

#include "flash.h"
#include <stdbool.h>

#include "io_cfg.h"
#include "sys_cfg.h"

/* WINBOND commands */
#define WINBOND_W_EN                        0x06    /* write enable */
#define WINBOND_W_DE                        0x04    /* write disable */
#define WINBOND_R_SR1                       0x05    /* read status reg 1 */
#define WINBOND_R_SR2                       0x35    /* read status reg 2 */
#define WINBOND_W_SR                        0x01    /* write status reg */
#define WINBOND_PAGE_PGM                    0x02    /* page program */
#define WINBOND_QPAGE_PGM                   0x32    /* quad input page program */
#define WINBOND_BLK_E_64K                   0xD8    /* block erase 64kb */
#define WINBOND_BLK_E_32K                   0x52    /* block erase 32kb */
#define WINBOND_SECTOR_E                    0x20    /* sector erase 4kb */
#define WINBOND_CHIP_ERASE                  0xC7    /* chip erase */
#define WINBOND_CHIP_ERASE2                 0x60    /* =chip_erase */
#define WINBOND_E_SUSPEND                   0x75    /* erase suspend */
#define WINBOND_E_RESUME                    0x7A    /* erase resume */
#define WINBOND_PDWN                        0xB9    /* power down */
#define WINBOND_HIGH_PERF_M                 0xA3    /* high performance mode */
#define WINBOND_CONT_R_RST                  0xFF    /* continuous read mode reset */
#define WINBOND_RELEASE                     0xAB    /* release power down or hpm/dev id (deprecated) */
#define WINBOND_R_MANUF_ID                  0x90    /* read manufacturer and dev id (deprecated) */
#define WINBOND_R_UNIQUE_ID                 0x4B    /* read unique id (suggested) */
#define WINBOND_R_JEDEC_ID                  0x9F    /* read jedec id = manuf+id (suggested) */
#define WINBOND_READ                        0x03
#define WINBOND_FAST_READ                   0x0B
#define WINBOND_READ_STATUS_REG_1           0x05

#define WINBOND_SR1_BUSY_MASK               0x01    /* status register 1 busy mask */
#define WINBOND_SR1_WEN_MASK                0x02    /* status register 1 write enable mask */

#define WINBOND_WINBOND_MANUF               0xEF    /* winbond manufacturer id */

#define WINBOND_DEFAULT_TIMEOUT             200     /* default timeout */

/* flash enable debug */
#define FLASH_DBG_EN						0

/******************************************************************************
* declare static function
*******************************************************************************/
static void flash_set_write_enable(bool);
static uint8_t flash_wait_to_idle();

/******************************************************************************
* define static function
*******************************************************************************/
void flash_set_write_enable(bool e) {
	flash_cs_low();

	if (e == true) {
		spi1_transfer(WINBOND_W_EN);
	}
	else {
		spi1_transfer(WINBOND_W_DE);
	}

	flash_cs_high();

	sys_ctrl_delay_us(100);
}

uint8_t flash_wait_to_idle() {
	uint8_t reg_1 = 0;
	uint32_t time_out_counter = 10000;	/* 10s */

	flash_cs_low();
	sys_ctrl_delay_us(100);

	spi1_transfer(WINBOND_READ_STATUS_REG_1);

	do {
		reg_1 = spi1_transfer(0x00);
		time_out_counter --;
		sys_ctrl_delay_us(100);
	} while ((reg_1 & 1) && time_out_counter);

	flash_cs_high();

	if (time_out_counter) {
		return FLASH_DRIVER_OK;
	}

	return FLASH_DRIVER_NG;
}

/******************************************************************************
* define public function
*******************************************************************************/
uint8_t flash_read(uint32_t address, uint8_t* pbuf, uint32_t len) {
	uint16_t i;

#if (FLASH_DBG_EN == 1)
	SYS_PRINT("[flash_read] add:0x%x\t%d\n", address, len);
#endif

	flash_wait_to_idle();

	flash_cs_low();

	spi1_transfer(WINBOND_READ);

	spi1_transfer(address >> 16);
	spi1_transfer(address >> 8);
	spi1_transfer(address);

	for(i = 0; i < len; i++) {
		pbuf[i] = spi1_transfer(0x00);
	}

	flash_cs_high();

	return FLASH_DRIVER_OK;
}

uint8_t flash_write(uint32_t address, uint8_t* pbuf, uint32_t len) {
	bool next_page_flag = true;
	uint32_t pbuf_index = 0;

#if (FLASH_DBG_EN == 1)
	SYS_PRINT("[flash_write] add:0x%x\t%d\n", address, len);
#endif

	while (len) {
		if (next_page_flag) {
			next_page_flag = false;

			flash_wait_to_idle();
			flash_set_write_enable(true);

			flash_cs_low();

			spi1_transfer(WINBOND_PAGE_PGM);

			spi1_transfer((address >> 16) & 0xff);
			spi1_transfer((address >> 8)  & 0xff);
			spi1_transfer((address >> 0)  & 0xff);
		}

		spi1_transfer(pbuf[pbuf_index++]);

		address++;
		len--;

		if ((address & 0xff) == 0) {
			next_page_flag = true;
			if (len) {
				flash_cs_high();
			}
		}
	}

	flash_cs_high();

	return flash_wait_to_idle();
}

uint8_t flash_erase_sector(uint32_t address) {

	if (address % 0x1000) {
		return FLASH_DRIVER_NG;
	}

#if (FLASH_DBG_EN == 1)
	SYS_PRINT("[flash_erase_sector] add:0x%x\n", address);
#endif

	flash_wait_to_idle();
	flash_set_write_enable(true);

	flash_cs_low();

	spi1_transfer(WINBOND_SECTOR_E);

	spi1_transfer(address >> 16);
	spi1_transfer(address >> 8);
	spi1_transfer(address);

	flash_cs_high();

	sys_ctrl_delay_us(100);

	return flash_wait_to_idle();
}

uint8_t flash_erase_block_32k(uint32_t address) {
	if (address % 0x8000) {
		return FLASH_DRIVER_NG;
	}

#if (FLASH_DBG_EN == 1)
	SYS_PRINT("[flash_erase_block_32k] add:0x%x\n", address);
#endif

	flash_wait_to_idle();
	flash_set_write_enable(true);

	flash_cs_low();

	spi1_transfer(WINBOND_BLK_E_32K);

	spi1_transfer(address >> 16);
	spi1_transfer(address >> 8);
	spi1_transfer(address);

	flash_cs_high();

	sys_ctrl_delay_us(100);

	return flash_wait_to_idle();
}

uint8_t flash_erase_block_64k(uint32_t address) {
	if (address % 0x10000) {
		return FLASH_DRIVER_NG;
	}

#if (FLASH_DBG_EN == 1)
	SYS_PRINT("[flash_erase_block_64k] add:0x%x\n", address);
#endif

	flash_wait_to_idle();
	flash_set_write_enable(true);

	flash_cs_low();

	spi1_transfer(WINBOND_BLK_E_64K);

	spi1_transfer(address >> 16);
	spi1_transfer(address >> 8);
	spi1_transfer(address);

	flash_cs_high();

	sys_ctrl_delay_us(100);

	return flash_wait_to_idle();
}

uint8_t  flash_erase_full() {
#if (FLASH_DBG_EN == 1)
	SYS_PRINT("[flash_erase_full]\n");
#endif

	flash_wait_to_idle();
	flash_set_write_enable(true);

	flash_cs_low();

	spi1_transfer(WINBOND_CHIP_ERASE2);

	flash_cs_high();

	sys_ctrl_delay_us(100);

	return flash_wait_to_idle();
}

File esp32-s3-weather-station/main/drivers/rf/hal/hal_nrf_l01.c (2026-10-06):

/* Copyright (c) 2007 Nordic Semiconductor. All Rights Reserved.
 *
 * The information contained herein is property of Nordic Semiconductor ASA.
 * Terms and conditions of usage are described in detail in NORDIC
 * SEMICONDUCTOR STANDARD SOFTWARE LICENSE AGREEMENT. 
 *
 * Licensees are granted free, non-transferable use of the information. NO
 * WARRENTY of ANY KIND is provided. This heading must NOT be removed from
 * the file.
 *
 * $LastChangedRevision: 2132 $
 */ 

 /** @file
 *
 * @author Runar Kjellhaug
 *
 */

#include <stdint.h>
#include <stdbool.h>

#include "nordic_common.h"
#include "hal_nrf.h"
#include "hal_nrf_reg.h"

#define HAL_NRF_SET_BIT(pos) ((uint8_t) (1<<( (uint8_t) (pos) )))
#define UINT8(t) ((uint8_t) (t))

void hal_nrf_set_irq_mode(hal_nrf_irq_source_t int_source, bool irq_state)
{
  if(irq_state)
  {
	hal_nrf_write_reg(CONFIG, hal_nrf_read_reg(CONFIG) & ~HAL_NRF_SET_BIT(int_source));
  }
  else
  {
	hal_nrf_write_reg(CONFIG, hal_nrf_read_reg(CONFIG) | HAL_NRF_SET_BIT(int_source));
  }
}

uint8_t hal_nrf_get_clear_irq_flags(void)
{
  return hal_nrf_write_reg(NRF_STATUS, (BIT_6|BIT_5|BIT_4)) & (BIT_6|BIT_5|BIT_4);
}

void hal_nrf_clear_irq_flag(hal_nrf_irq_source_t int_source)
{
  hal_nrf_write_reg(NRF_STATUS, HAL_NRF_SET_BIT(int_source));
}
 
bool hal_nrf_get_irq_mode(uint8_t int_type)
{
  if(hal_nrf_read_reg(CONFIG) & HAL_NRF_SET_BIT(int_type))
    return false;
  else
    return true;
}

uint8_t hal_nrf_get_irq_flags(void)
{
  return hal_nrf_nop() & (BIT_6|BIT_5|BIT_4);
}

void hal_nrf_set_crc_mode(hal_nrf_crc_mode_t crc_mode)
{
  hal_nrf_write_reg(CONFIG, (hal_nrf_read_reg(CONFIG) & ~(BIT_3|BIT_2)) | (UINT8(crc_mode)<<2));
}

void hal_nrf_open_pipe(hal_nrf_address_t pipe_num, bool auto_ack)
{
  switch(pipe_num)
  {
    case HAL_NRF_PIPE0:
    case HAL_NRF_PIPE1:
    case HAL_NRF_PIPE2:
    case HAL_NRF_PIPE3:
    case HAL_NRF_PIPE4:
    case HAL_NRF_PIPE5:
	  hal_nrf_write_reg(EN_RXADDR, hal_nrf_read_reg(EN_RXADDR) | HAL_NRF_SET_BIT(pipe_num));

      if(auto_ack)
		hal_nrf_write_reg(EN_AA, hal_nrf_read_reg(EN_AA) | HAL_NRF_SET_BIT(pipe_num));
      else
		hal_nrf_write_reg(EN_AA, hal_nrf_read_reg(EN_AA) & ~HAL_NRF_SET_BIT(pipe_num));
      break;

    case HAL_NRF_ALL:
	  hal_nrf_write_reg(EN_RXADDR, ((uint8_t)~(BIT_7|BIT_6)));

      if(auto_ack)
		hal_nrf_write_reg(EN_AA, ((uint8_t)~(BIT_7|BIT_6)));
      else
        hal_nrf_write_reg(EN_AA, 0);
      break;
      
    default:
      break;
  }
}

void hal_nrf_close_pipe(hal_nrf_address_t pipe_num)
{
  switch(pipe_num)
  {
    case HAL_NRF_PIPE0:
    case HAL_NRF_PIPE1:
    case HAL_NRF_PIPE2:
    case HAL_NRF_PIPE3:
    case HAL_NRF_PIPE4:
    case HAL_NRF_PIPE5:
	  hal_nrf_write_reg(EN_RXADDR, hal_nrf_read_reg(EN_RXADDR) & ~HAL_NRF_SET_BIT(pipe_num));
	  hal_nrf_write_reg(EN_AA, hal_nrf_read_reg(EN_AA) & ~HAL_NRF_SET_BIT(pipe_num));
      break;
    
    case HAL_NRF_ALL:
      hal_nrf_write_reg(EN_RXADDR, 0);
      hal_nrf_write_reg(EN_AA, 0);
      break;
      
    default:
      break;
  }
}

void hal_nrf_set_address(hal_nrf_address_t address, uint8_t *addr)
{
  switch(address)
  {
    case HAL_NRF_TX:
    case HAL_NRF_PIPE0:
    case HAL_NRF_PIPE1:
      hal_nrf_write_multibyte_reg((uint8_t) address, addr, 0);
      break;

    case HAL_NRF_PIPE2:
    case HAL_NRF_PIPE3:
    case HAL_NRF_PIPE4:
    case HAL_NRF_PIPE5:
      hal_nrf_write_reg(RX_ADDR_P0 + (uint8_t) address, *addr);
      break;

    default:
      break;
  }
}

void hal_nrf_set_auto_retr(uint8_t retr, uint16_t delay)
{
  hal_nrf_write_reg(SETUP_RETR, (((delay/250)-1)<<4) | retr);
}

void hal_nrf_set_address_width(hal_nrf_address_width_t address_width)
{
  hal_nrf_write_reg(SETUP_AW, (UINT8(address_width) - 2));
}

void hal_nrf_set_rx_pload_width(uint8_t pipe_num, uint8_t pload_width)
{
  hal_nrf_write_reg(RX_PW_P0 + pipe_num, pload_width);
}

uint8_t hal_nrf_get_crc_mode(void)
{
  return (hal_nrf_read_reg(CONFIG) & (BIT_3|BIT_2)) >> CRCO;
}

uint8_t hal_nrf_get_pipe_status(uint8_t pipe_num)
{
  uint8_t en_rx, en_aa;

  en_rx = hal_nrf_read_reg(EN_RXADDR) & (1<<pipe_num);
  en_aa = hal_nrf_read_reg(EN_AA) & (1<<pipe_num);

  en_rx >>= pipe_num;
  en_aa >>= pipe_num;

  return (en_aa << 1) + en_rx;
}

uint8_t hal_nrf_get_address(uint8_t address, uint8_t *addr)
{
  switch(address)
  {
    case HAL_NRF_PIPE0:
    case HAL_NRF_PIPE1:
    case HAL_NRF_TX:
      return hal_nrf_read_multibyte_reg(address, addr);

    default:
      *addr = hal_nrf_read_reg(RX_ADDR_P0 + address);
      return hal_nrf_get_address_width();
  }
}

uint8_t hal_nrf_get_auto_retr_status(void)
{
  return hal_nrf_read_reg(OBSERVE_TX);
}

uint8_t hal_nrf_get_packet_lost_ctr(void)
{
  return (hal_nrf_read_reg(OBSERVE_TX) & (BIT_7|BIT_6|BIT_5|BIT_4)) >> 4;
}

uint8_t hal_nrf_get_address_width(void)
{
  return (hal_nrf_read_reg(SETUP_AW) + 2);
}

uint8_t hal_nrf_get_rx_pload_width(uint8_t pipe_num)
{
  return hal_nrf_read_reg(RX_PW_P0 + pipe_num);
}

void hal_nrf_set_operation_mode(hal_nrf_operation_mode_t op_mode)
{
  if(op_mode == HAL_NRF_PRX)
  {
    hal_nrf_write_reg(CONFIG, (hal_nrf_read_reg(CONFIG) | (1<<PRIM_RX)));
  }
  else
  {
    hal_nrf_write_reg(CONFIG, (hal_nrf_read_reg(CONFIG) & ~(1<<PRIM_RX)));
  }
}

void hal_nrf_set_power_mode(hal_nrf_pwr_mode_t pwr_mode)
{
  if(pwr_mode == HAL_NRF_PWR_UP)
  {
    hal_nrf_write_reg(CONFIG, (hal_nrf_read_reg(CONFIG) | (1<<PWR_UP)));
  }
  else
  {
    hal_nrf_write_reg(CONFIG, (hal_nrf_read_reg(CONFIG) & ~(1<<PWR_UP)));
  }
}

void hal_nrf_set_rf_channel(uint8_t channel)
{
  hal_nrf_write_reg(RF_CH, channel);
}

void hal_nrf_set_output_power(hal_nrf_output_power_t power)
{
  hal_nrf_write_reg(RF_SETUP, (hal_nrf_read_reg(RF_SETUP) & ~((1<<RF_PWR1)|(1<<RF_PWR0))) | (UINT8(power)<<1));
}

void hal_nrf_set_datarate(hal_nrf_datarate_t datarate)
{
  if(datarate == HAL_NRF_1MBPS)
  {
    hal_nrf_write_reg(RF_SETUP, (hal_nrf_read_reg(RF_SETUP) & ~(1<<RF_DR)));
  }
  else
  {
    hal_nrf_write_reg(RF_SETUP, (hal_nrf_read_reg(RF_SETUP) | (1<<RF_DR)));
  }
}

uint8_t hal_nrf_get_operation_mode(void)
{
  return (hal_nrf_read_reg(CONFIG) & (1<<PRIM_RX)) >> PRIM_RX;
}

uint8_t hal_nrf_get_power_mode(void)
{
  return (hal_nrf_read_reg(CONFIG) & (1<<PWR_UP)) >> PWR_UP;
}

uint8_t hal_nrf_get_rf_channel(void)
{
  return hal_nrf_read_reg(RF_CH);
}

uint8_t hal_nrf_get_output_power(void)
{
  return (hal_nrf_read_reg(RF_SETUP) & ((1<<RF_PWR1)|(1<<RF_PWR0))) >> RF_PWR0;
}

uint8_t hal_nrf_get_datarate(void)
{
  return (hal_nrf_read_reg(RF_SETUP) & (1<<RF_DR)) >> RF_DR;
}

bool hal_nrf_rx_fifo_empty(void)
{
 if(hal_nrf_get_rx_data_source()==7)
  {
    return true;
  }
  else
  {
    return false;
  }
}

bool hal_nrf_rx_fifo_full(void)
{
  return (bool)((hal_nrf_read_reg(FIFO_STATUS) >> RX_EMPTY) & 1);
}

bool hal_nrf_tx_fifo_empty(void)
{
  return (bool)((hal_nrf_read_reg(FIFO_STATUS) >> TX_EMPTY) & 1);
}

bool hal_nrf_tx_fifo_full(void)
{
  return (bool)((hal_nrf_read_reg(FIFO_STATUS) >> TX_FIFO_FULL) & 1);
}
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
